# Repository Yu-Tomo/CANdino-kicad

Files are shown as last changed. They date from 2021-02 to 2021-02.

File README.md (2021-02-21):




# CANdino-kicad

CAN用IC搭載のArduino互換機になります。

Qiitaの記事はこちらから→https://qiita.com/Yu-Tomo/items/e30f2b3abf415f76f6f1

※基盤を発注は自己責任でお願いします。

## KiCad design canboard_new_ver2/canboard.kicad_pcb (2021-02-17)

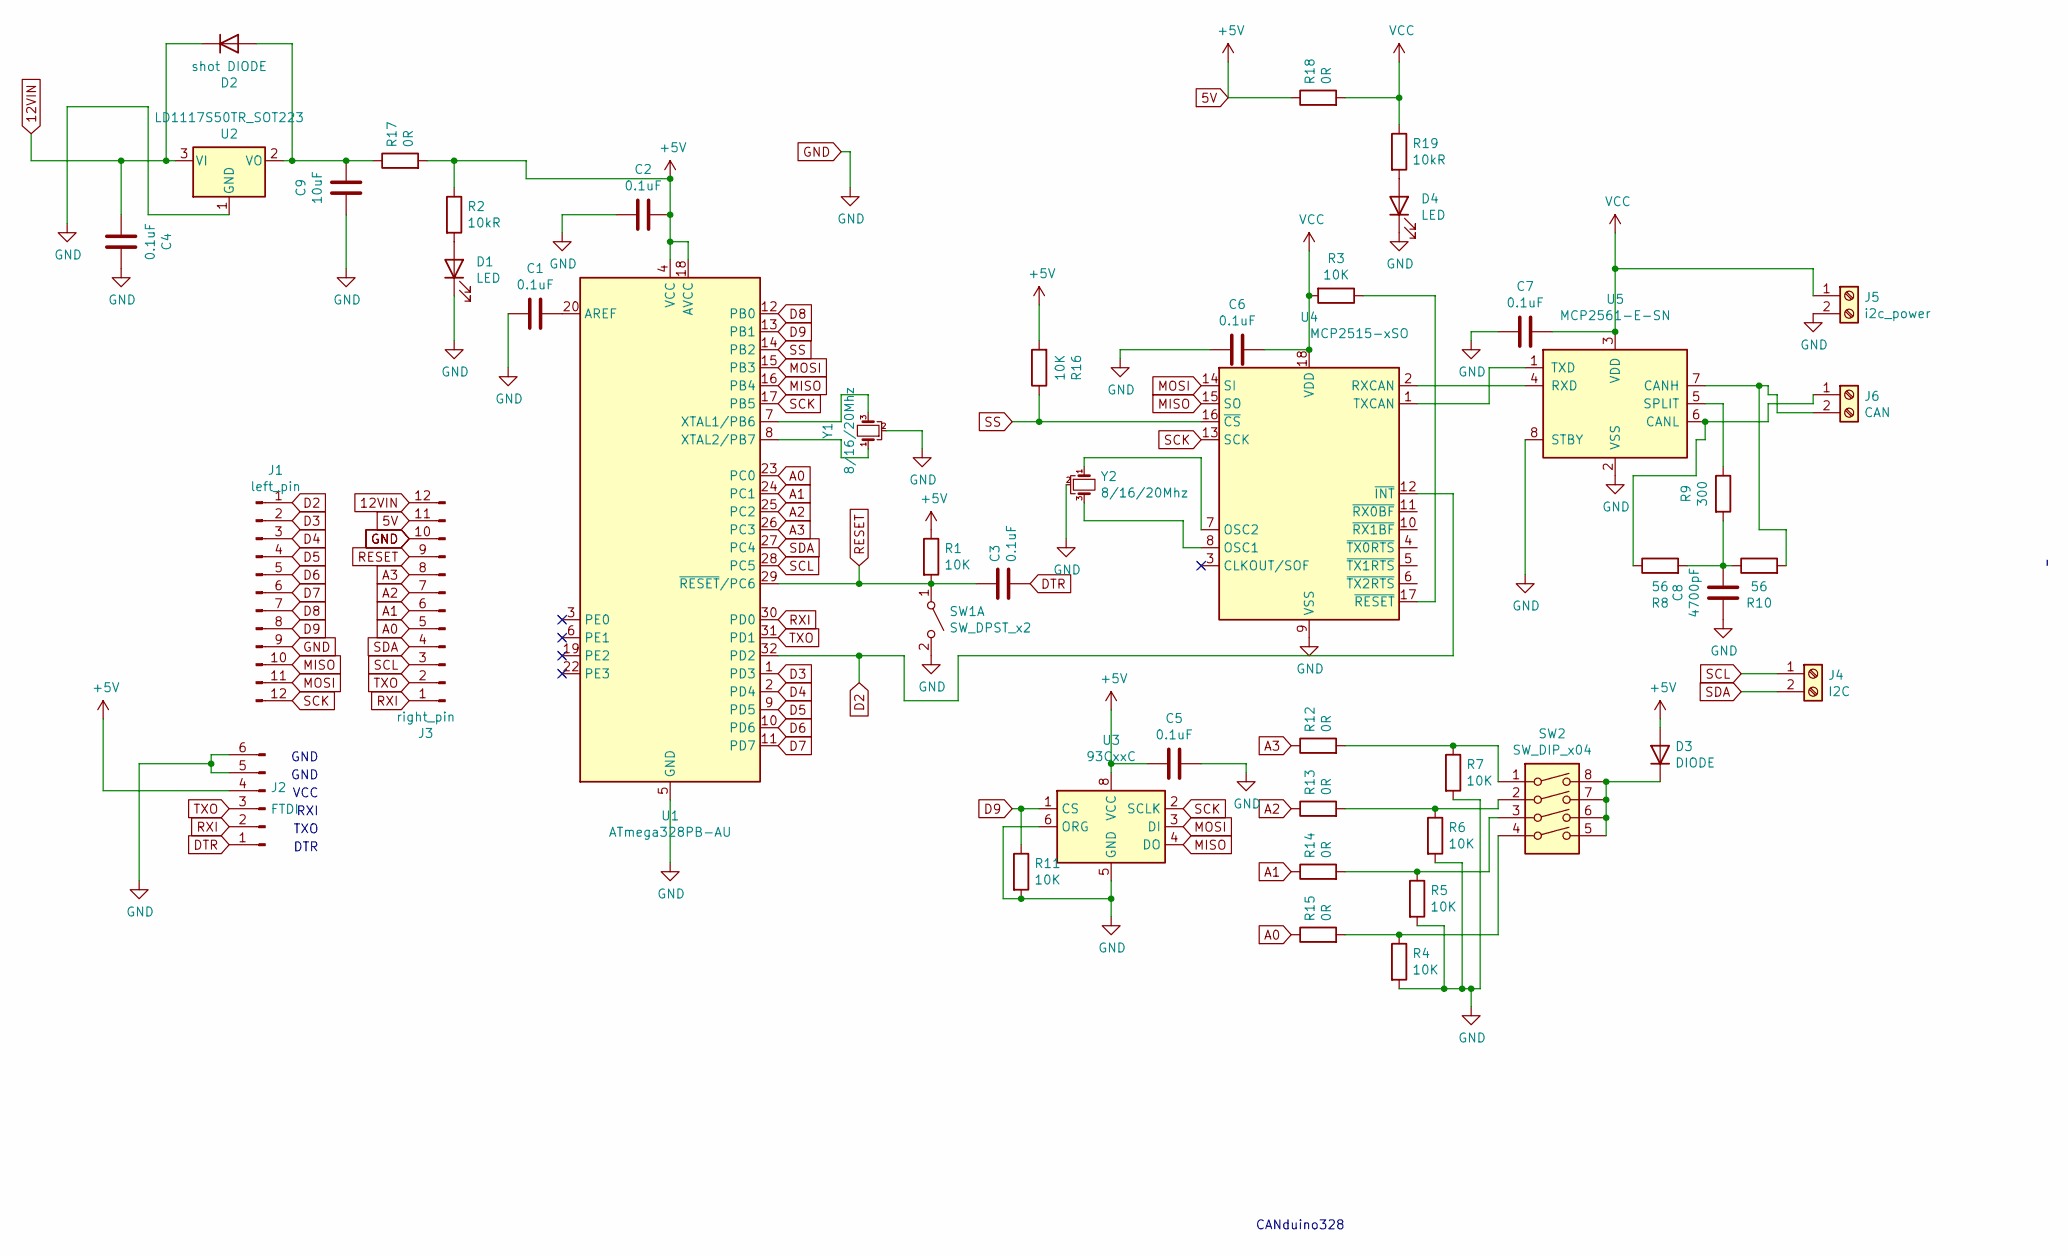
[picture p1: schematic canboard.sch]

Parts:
C1, C2, C3, C4, C5, C6, C7: 0.1uF; C_0402_1005Metric
C8: 4700pF; C_0603_1608Metric
C9: 10uF; C_0805_2012Metric
D1, D4: LED; LED_0603_1608Metric
D2: shot DIODE; D_0805_2012Metric
D3: DIODE; D_0805_2012Metric
J1: left_pin; PinHeader_1x12_P2.54mm_Vertical
J2: FTDI; PinHeader_1x06_P2.54mm_Vertical
J3: right_pin; PinHeader_1x12_P2.54mm_Vertical
J4: I2C; TerminalBlock_TE_282834-2_1x02_P2.54mm_Horizontal
J5: i2c_power; TerminalBlock_TE_282834-2_1x02_P2.54mm_Horizontal
J6: CAN; TerminalBlock_TE_282834-2_1x02_P2.54mm_Horizontal
R1, R3, R4, R5, R6, R7, R11, R16: 10K; R_0603_1608Metric
R2, R19: 10kR; R_0603_1608Metric
R8, R10: 56; R_1206_3216Metric
R9: 300; R_0603_1608Metric
R12, R13, R14, R15, R17, R18: 0R; R_0603_1608Metric
SW1: SW_DPST_x2; SW_SPST_REED_CT05-XXXX-J1
SW2: SW_DIP_x04; SW_DIP_SPSTx04_Slide_Copal_CHS-04B_W7.62mm_P1.27mm
U1: ATmega328PB-AU; TQFP-32_7x7mm_P0.8mm
U2: LD1117S50TR_SOT223; SOT-223-3_TabPin2
U3: 93CxxC; DIP-8_W7.62mm_Socket
U4: MCP2515-xSO; SOIC-18W_7.5x11.6mm_P1.27mm
U5: MCP2561-E-SN; SOIC-8_3.9x4.9mm_P1.27mm
Y1, Y2: 8/16/20Mhz; Resonator_SMD_muRata_CSTxExxV-3Pin_3.0x1.1mm_HandSoldering

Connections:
5V: C2.1, C5.2, D3.1 (A), J2.4, J3.11, R1.1, R2.1, R16.2, R17.2, R18.1, U1.4 (VCC), U1.18 (AVCC), U3.8 (VCC)
12VIN: C4.2, D2.2 (K), J3.12, U2.3 (VI)
A0: J3.5, R15.1, U1.23 (PC0)
A1: J3.6, R14.1, U1.24 (PC1)
A2: J3.7, R13.1, U1.25 (PC2)
A3: J3.8, R12.1, U1.26 (PC3)
D2: J1.1, U1.32 (PD2), U4.12 (~INT)
D3: J1.2, U1.1 (PD3)
D4: J1.3, U1.2 (PD4)
D5: J1.4, U1.9 (PD5)
D6: J1.5, U1.10 (PD6)
D7: J1.6, U1.11 (PD7)
D8: J1.7, U1.12 (PB0)
D9: J1.8, R11.1, U1.13 (PB1), U3.1 (CS)
DTR: C3.1, J2.1
GND: C1.2, C2.2, C4.1, C5.1, C6.2, C7.2, C8.2, C9.2, D1.1 (K), D4.1 (K), J1.9, J2.5, J2.6, J3.10, J5.2, R4.2, R5.2, R6.2, R7.2, R11.2, SW1.2 (B), U1.5 (GND), U1.21 (GND), U2.1 (GND), U3.5 (GND), U3.6 (ORG), U4.9 (VSS), U5.2 (VSS), U5.8 (STBY), Y1.2, Y2.2
MISO: J1.10, U1.16 (PB4), U3.4 (DO), U4.15 (SO)
MOSI: J1.11, U1.15 (PB3), U3.3 (DI), U4.14 (SI)
unnamed: C1.1, U1.20 (AREF)
unnamed: C8.1, R8.2, R9.2, R10.1
unnamed: C9.1, D2.1 (A), R17.1, U2.2 (VO)
unnamed: D1.2 (A), R2.2
unnamed: D3.2 (K), SW2.5, SW2.6, SW2.7, SW2.8
unnamed: D4.2 (A), R19.2
unnamed: J6.1, R8.1, U5.6 (CANL)
unnamed: J6.2, R10.2, U5.7 (CANH)
unnamed: R3.1, U4.17 (~RESET)
unnamed: R9.1, U5.5 (SPLIT)
unnamed: R7.1, R12.2, SW2.1
unnamed: R6.1, R13.2, SW2.2
unnamed: R5.1, R14.2, SW2.3
unnamed: R4.1, R15.2, SW2.4
unnamed: U1.7 (XTAL1/PB6), Y1.3
unnamed: U1.8 (XTAL2/PB7), Y1.1
unnamed: U4.1 (TXCAN), U5.1 (TXD)
unnamed: U4.2 (RXCAN), U5.4 (RXD)
unnamed: U4.7 (OSC2), Y2.1
unnamed: U4.8 (OSC1), Y2.3
RESET: C3.2, J3.9, R1.2, SW1.1 (A), U1.29 (~RESET~/PC6)
RXI: J2.2, J3.1, U1.30 (PD0)
SCK: J1.12, U1.17 (PB5), U3.2 (SCLK), U4.13 (SCK)
SCL: J3.3, J4.1, U1.28 (PC5)
SDA: J3.4, J4.2, U1.27 (PC4)
SS: R16.1, U1.14 (PB2), U4.16 (~CS)
TXO: J2.3, J3.2, U1.31 (PD1)
VCC: C6.1, C7.1, J5.1, R3.2, R18.2, R19.1, U4.18 (VDD), U5.3 (VDD)

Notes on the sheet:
GND
VCC
DTR
TXO
RXI
CANduino328

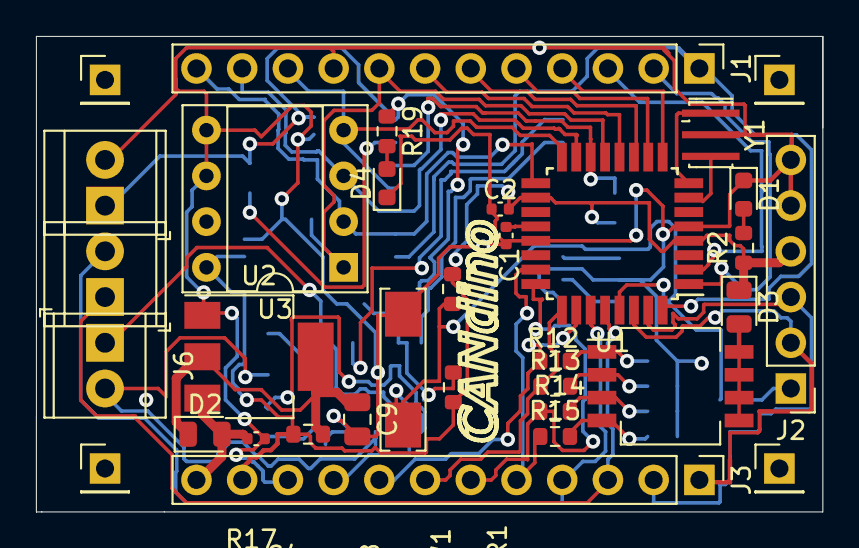
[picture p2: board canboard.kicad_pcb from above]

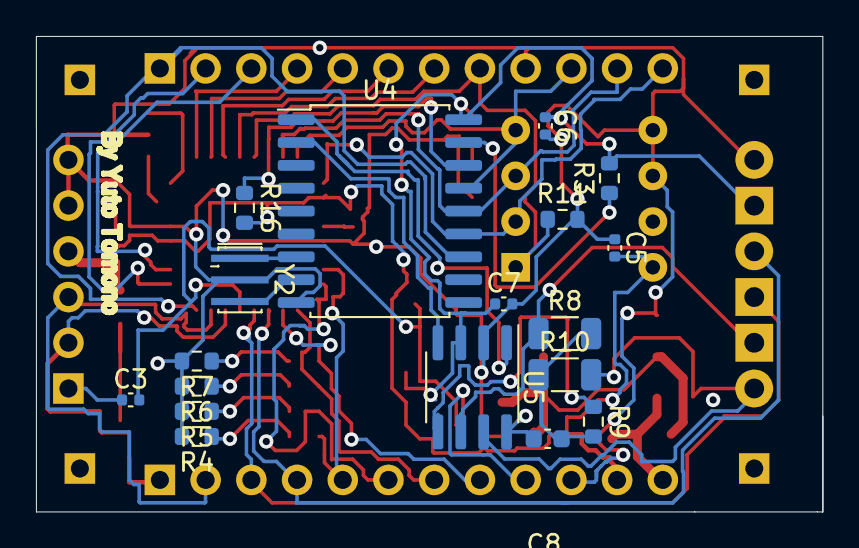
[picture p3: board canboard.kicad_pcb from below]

Board: 2 copper layers, 43.7 x 26.4 mm, 47 parts (18 on the bottom side), 46 nets.
